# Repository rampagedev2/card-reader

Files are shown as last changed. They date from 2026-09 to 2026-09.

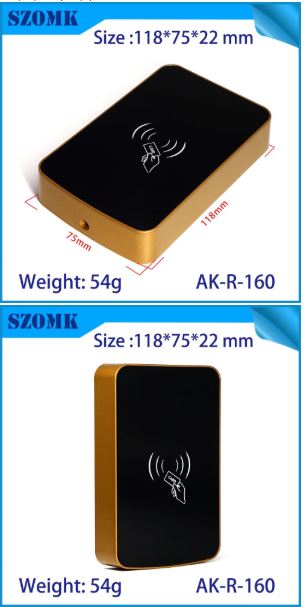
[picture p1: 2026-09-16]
enclosure/1.JPG

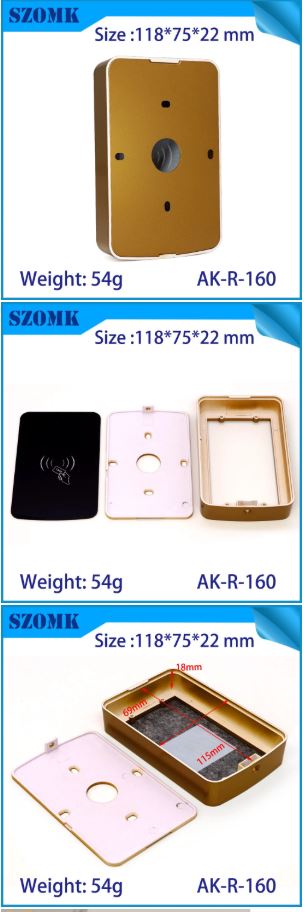
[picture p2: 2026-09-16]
enclosure/2.JPG

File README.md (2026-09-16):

# Card Reader — GD32F407VET6 + RC522

Desktop USB card reader: user **places the card on top**; RFID (RC522 module), buzzer, USB Mass Storage, ECC.

| Item | Spec |
|---|---|
| MCU | GigaDevice **GD32F407VET6** (Cortex-M4 @ 168 MHz, LQFP-100) |
| RFID | **RC522 ready module** (SPI via header J3) |
| Storage | **Custom USB MSC** (MCU internal Flash / virtual disk — no SPI NOR) |
| USB | USB-C (device FS), customized Mass Storage Class |
| Audio | Passive piezo buzzer |
| Crypto | Software ECC (secp256r1) on Cortex-M4 FPU |
| Power | USB 5 V → 3.3 V LDO |
| PCB | Fit AK-R-160 (~110 × 65 mm max), 2-layer FR-4 |
| Enclosure | **SZOMK AK-R-160** (118×75×22) — CNC card recess + LED + Type-C |

## Features

1. **Read Card** — MIFARE Classic / Ultralight / ISO14443A via SPI to MFRC522  
2. **Buzzer** — PWM-driven piezo for tap / OK / error tones  
3. **USB Mass Storage** — appears as a removable drive; card UIDs / logs written as files  
4. **ECC calculation** — sign / verify card payloads (mbedTLS / micro-ecc)

## Folder map

```
bom/           Bill of materials + pricing (qty 500, China)
docs/          Architecture, pin map, production notes
schematic/     Multi-sheet schematic (SVG + netlist)
pcb/           PCB layout, stackup, design rules
enclosure/     Mechanical design (OpenSCAD + drawings)
firmware/      Feature map / suggested stack
```

## Cost snapshot (500 units, China)

See the interactive cost canvas and `bom/BOM_500pcs.csv`.

| Category | Per unit | 500 batch |
|---|---|---|
| Electronics (parts + bare PCB) | ~$6.60 | ~$3,300 |
| AK-R-160 + CNC | ~$1.70 | ~$850 |
| **Total (hand build hardware)** | **~$8.30** | **~$4,150** |

Buy: https://www.chinaenclosure.com/products/SZOMK-Custom-IP54-abs-plastic-junction-box-RFID-enclosure-for-Card-reader-AK-R-160-118-75-22mm.html — Ops excluded.

## Quick start (hardware)

1. Review `docs/architecture.md` and `schematic/01_system.svg`  
2. Import netlist / redraw in KiCad from `schematic/` sheets  
3. Fabricate PCB per `pcb/design-rules.md` (JLCPCB recommended)  
4. Print enclosure prototype from `enclosure/card_reader_case.scad`  
5. Open `firmware/KEIL/CardReader.uvprojx` (ARMCC5, no HAL) — build & flash SWD

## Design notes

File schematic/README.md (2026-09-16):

# Schematics Index

Open SVG files in a browser, VS Code, or Inkscape.

| Sheet | File | Content |
|---|---|---|
| 01 | `01_system.svg` | Block diagram / system overview |
| 02 | `02_power.svg` | USB-C, ESD, ferrite, LDO 3.3 V |
| 03 | `03_mcu.svg` | GD32F407VET6 pin connections |
| 04 | `04_rfid.svg` | RC522 **module** header J3 wiring |
| 05 | `05_usb_flash_buzzer.svg` | Custom USB MSC, buzzer, LEDs, ECC notes |

Supporting: `netlist.txt`

## Path to Gerbers

1. Create KiCad 8 project  
2. Redraw sheets using these SVGs + `docs/pin-map.md`  
3. Assign footprints (LQFP-100, QFN-32, SOIC-8, …)  
4. Import PCB floorplan from `../pcb/pcb_layout.svg`  
5. Run DRC per `../pcb/design-rules.md`  
6. Plot Gerbers for JLCPCB  

These SVGs are **design-complete electrically** for quoting and review; KiCad redraw is the manufacturing gate.

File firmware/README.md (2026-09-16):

# Firmware — GD32F407VET6 bare-metal (no HAL) + legacy Keil

## Rules

- **No HAL / no SPL** — register-level drivers + minimal CMSIS map (`CMSIS/gd32f407_regs.h`)
- **Legacy Keil** — µVision project uses **ARM Compiler 5 (ARMCC)**, not ARMClang
- Open: `KEIL/CardReader.uvprojx`

## Build (Keil MDK)

1. Install Keil MDK-ARM with **ARMCC V5** (legacy compiler pack)
2. Open `firmware/KEIL/CardReader.uvprojx`
3. If prompted for device pack, use generic **ARMCM4_FP** (or install GigaDevice GD32F4 pack for flash algo)
4. Project → Options → Target → confirm **ARMCC V5**
5. Build (`F7`) → flash via SWD (CMSIS-DAP / J-Link)

Output: `KEIL/Objects/CardReader.hex`

## Tree

```
firmware/
  CMSIS/gd32f407_regs.h     Register map (no vendor HAL)
  Startup/startup_gd32f407.s  ARMCC startup + vectors
  Inc/                      board.h bsp.h spi_bus.h usb_msc.h
  Src/                      system / bsp / spi / usb_msc / main
  Middlewares/mfrc522/      RC522 SPI driver
  Middlewares/ecc/          ECC API (demo signer; swap micro-ecc later)
  KEIL/CardReader.uvprojx   Legacy Keil project
  KEIL/CardReader.sct       Scatter file
```

## Verification

See **[VERIFY.md](VERIFY.md)** — register-map bugs fixed; USB BOT + real ECDSA still open.

## Features wired

| Feature | Status |
|---|---|
| 8 MHz HXTAL → 168 MHz PLL + FMC WS | OK (fixed) |
| LEDs PB1/PB2 | OK |
| Buzzer PB0 TIMER2 PWM | OK (base/enable fixed) |
| SPI0 + MFRC522 4-byte UID | OK |
| Virtual FAT MSC (UID.TXT, LOG.CSV, UID.SIG) | RAM image OK |
| USBFS device enumeration / BOT | Skeleton only — not host-mountable yet |
| ECC sign on UID | Demo MAC only — not ECDSA |

## Pin map

See `docs/pin-map.md` (SPI1/SPI0 on PA4–7, RC522 RST PC4, USB PA11/12).

## Flash / debug

- SWD: PA13/PA14
- Algorithm: use GD32F4xx flash algo from GigaDevice Keil pack when available

## Optional: real ECDSA P-256

Drop [micro-ecc](https://github.com/kmackay/micro-ecc) `.c/.h` into `Middlewares/ecc/` and replace the body of `ecc_sign` / `ecc_verify` — keep the same headers so `main.c` stays unchanged.

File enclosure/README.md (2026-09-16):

# Enclosure — SZOMK AK-R-160 (selected)

Selected: **[AK-R-160](https://www.chinaenclosure.com/products/SZOMK-Custom-IP54-abs-plastic-junction-box-RFID-enclosure-for-Card-reader-AK-R-160-118-75-22mm.html)**

| | |
|--|--|
| Maker | SZOMK / Shenzhen OMK Electronics (China) |
| Part | **AK-R-160** |
| Size | **118 × 75 × 22 mm** |
| Material | ABS |
| Color | Black (custom OK) |
| Weight | 54 g |
| Battery | **None** |
| IP | IP54 |
| Contact | ivy@szomk.com.cn · https://szokm.en.alibaba.com/ |

Also: https://www.chinaenclosure.com/products/Shenzhen-new-product-abs-plastic-access-control-card-reader-118X75X22mm-enclosure-supply-AK-R-160.html

## Features we need

| Feature | How |
|---|-----|
| **Card place** | CNC lid recess **86 × 54 × 0.8 mm** (ISO card) |
| **LED** | CNC **2 × ø3.0 mm** beside recess |
| **USB Type-C** | CNC **9.0 × 3.5 mm** on end wall |
| Logo | Blank / no logo |

Height **22 mm** fits RC522 module better than AK-R-107 (17 mm). Lid fits ISO card on top.

## PCB fit

Target PCB ≈ **110 × 65 mm** max (confirm with seller CAD). Current design should be sized to this shell.

## Order wording

> SZOMK **AK-R-160**, qty 500, black, blank no logo, **no battery**.  
> CNC: lid card recess **86×54×0.8 mm**; **2× LED ø3.0 mm**; Type-C **9.0×3.5 mm**.  
> Send CAD/PDF and 1–3 sample before mass run.

## Cost (est. @500)

| Item | USD |
|---|-----|
| AK-R-160 blank | ~1.20 |
| Card recess + Type-C + 2× LED CNC | ~0.50 |
| **Enclosure** | **~$1.70** |

Parts+PCB ~$6.60 → **~$8.30 / unit**, **~$4,150 / 500**.

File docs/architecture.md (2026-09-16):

# System Architecture

**UX:** User **places the card on top** of the device (recessed lid). RC522 under the lid reads it.

## Block diagram

```
              [ CARD on top ]
                    |
 USB-C 5V -> ESD -> LDO 3.3V -+- GD32F407VET6
                              +- RC522 MODULE (under lid, antenna up)
                              +- Buzzer / LEDs
                              +- Custom USB MSC (MCU Flash/RAM)
```

## Subsystems

### MCU
GD32F407VET6, 168 MHz, USB FS device, custom MSC + software ECC.

### RFID — RC522 module (top-read)
Ready **RC522** board under the lid. Card is placed **on the top surface**, not inserted in a slot.
Wired to SPI1 via header **J3**. Module antenna faces the lid.

### USB MSC
Custom firmware; no SPI NOR.

### Buzzer / LEDs
PWM piezo + status LEDs (feedback when card is read).

### Enclosure
**SZOMK AK-R-160** (118×75×22 mm): CNC top card recess + Type-C + LEDs. China, no battery.

## Power

| Rail | Load |
|---|---|
| 5V USB | LDO in, buzzer |
| 3V3 | MCU, **RC522 module**, LEDs |

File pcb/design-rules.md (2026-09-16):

# PCB Design Rules — Card Reader Rev A

## Board

| Parameter | Value |
|---|---|
| Size | **105 × 60 mm** (fit SZOMK AK-R-160 118×75×22; confirm CAD) |
| Layers | **2** (Top signal+RF, Bottom GND+signal) |
| Thickness | 1.6 mm FR-4 |
| Copper | 1 oz (35 µm) |
| Finish | HASL lead-free (ENIG optional +$ for LQFP fine pitch) |
| Min trace / space | 0.15 / 0.15 mm (6 / 6 mil) |
| Min via | 0.3 mm drill / 0.55 mm pad |
| Mask | Green, silkscreen white |
| Fab | JLCPCB / PCBWay China |

**Recommendation:** ENIG if LQFP-100 yield concerns; HASL is OK for qty 500 with good stencil.

## Stackup

```
TOP:    Components, RF antenna, SPI, USB short runs
DIELEC: 1.5 mm FR-4 core approx
BOTTOM: Solid GND pour, few jumpers, SWD pads
```

## Floorplan (see `pcb_layout.svg`)

```
Y=60 ┌──────────────────────────────────────┐
     │  [USB-C]    LDO    ESD               │  short edge = cable side
     │           [GD32F407 LQFP100]         │
     │  Buzzer  LEDs                        │
     │  J3 header ---- RC522 MODULE (top)   │  module under lid
     │                                      │
Y=0  └──────────────────────────────────────┘
   X=0                                  X=105
```
Fit: SZOMK **AK-R-160** (118×75×22). No onboard antenna — module antenna faces lid.

## Critical constraints

1. **Antenna keep-out**: no copper, no components, no screws in 45×45 mm zone except antenna traces & matching.
2. **USB DP/DM**: length match ±2 mm; run over continuous GND; ESD within 5 mm of connector.
3. **Crystal**: within 8 mm of OSC pins; guard GND ring.
4. **Decoupling**: 100 nF under/near each VDD pair; via to GND plane immediately.
5. **Thermal**: EP pad of MFRC522 via-stitched to GND.
6. **Mounting**: 4× M2.5 holes at corners, 3.2 mm ID, keep 5 mm copper clearance from antenna zone.

## Panelization (qty 500)

- Panel 2×3 or 2×4 with V-cut or mouse bites
- Fiducials for SMT
- Tooling strips 5–8 mm

## Gerber outputs expected

`GTL GBL GTS GBS GTO GBO GKO TXT(drill) CPL(pos) BOM`

Generate from KiCad after redrawing from SVG sheets + netlist.

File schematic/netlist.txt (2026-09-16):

# Card Reader Netlist (Rev F)
# RC522 module via J3 - no discrete MFRC522 / antenna on main PCB

NET VBUS : J1.VBUS U4.IN U5.VBUS L1.1 BZ1.POS
NET 3V3 : U4.OUT U1.VDD* J3.3V3 LED*_viaR
NET GND : J1.GND U4.GND U1.VSS* J3.GND Q1.S
NET USB_DP : J1.DP U5.DP U1.PA12
NET USB_DM : J1.DM U5.DM U1.PA11
NET SPI1_SCK : U1.PA5 J3.SCK
NET SPI1_MISO : U1.PA6 J3.MISO
NET SPI1_MOSI : U1.PA7 J3.MOSI
NET SPI1_NSS : U1.PA4 J3.SDA
NET RFID_RST : U1.PC4 J3.RST
NET RFID_IRQ : U1.PC5 J3.IRQ
NET BUZZER_PWM : U1.PB0 R_BUZ.1
NET BUZZER_GATE : R_BUZ.2 Q1.G
NET BUZZER_DRV : Q1.D BZ1.NEG D1.A
NET LED_STAT : U1.PB1 R_LED1.1
NET LED_RF : U1.PB2 R_LED2.1
NET SWDIO : U1.PA13 J2.2
NET SWCLK : U1.PA14 J2.3
NET NRST : U1.NRST J2.4 R_RST.1
NET OSC_IN : U1.OSC_IN X1.1 C4.1
NET OSC_OUT : U1.OSC_OUT X1.2 C5.1
NET BOOT0 : U1.BOOT0 R_BOOT.1

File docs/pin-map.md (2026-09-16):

# Pin Map — GD32F407VET6

Package: LQFP-100. RFID via **RC522 module** (not discrete chip).

## Power / reset / clock

| Pin | Net | Notes |
|-----|-----|---|
| 11, 19, 28, 50, 75, 100 | VDD | 3V3, 100 nF each + 10 uF bulk |
| 12, 18, 27, 49, 74, 99 | VSS | GND |
| 22 | VDDA | 3V3 via ferrite + 1 uF / 100 nF |
| 21 | VSSA | GND |
| 14 | NRST | 10k pull-up, 100 nF to GND |
| 23 | OSC_IN | 8 MHz X1 |
| 24 | OSC_OUT | 8 MHz X1 |
| 94 | BOOT0 | 10k to GND |

## USB

| Pin | Net | Function |
|-----|-----|---|
| 70 | PA11 | USB_DM |
| 71 | PA12 | USB_DP |

## SWD

| Pin | Net | Function |
|-----|-----|---|
| 72 | PA13 | SWDIO |
| 76 | PA14 | SWCLK |

## SPI0 (GD32) / SPI1 (STM alias) → RC522 module (J3)

PA4–PA7 AF5 = **SPI0** on GD32F407 (same pins as STM32 “SPI1”).

| MCU pin | Net | Module pin (typical) |
|---|-----|---|
| 3V3 | 3V3 | 3.3V |
| GND | GND | GND |
| PA5 | SPI0_SCK | SCK |
| PA6 | SPI0_MISO | MISO |
| PA7 | SPI0_MOSI | MOSI |
| PA4 | SPI0_NSS | SDA |
| PC4 | RFID_RST | RST |
| PC5 | RFID_IRQ | IRQ (optional) |

**Important:** Power module from **3.3V only** (not 5V).

## User I/O

| Pin | Net | Function |
|-----|-----|---|
| PB0 | BUZZER_PWM | TIM PWM |
| PB1 | LED_STATUS | Green |
| PB2 | LED_RF | Blue |

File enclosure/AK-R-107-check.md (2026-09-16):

# AK-R-107 check (superseded)

**Selected enclosure is now AK-R-160** (118×75×22). See `enclosure/README.md`.

AK-R-107 (118×75×17) was too short for RC522. Kept for history only.

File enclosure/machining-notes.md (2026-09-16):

# Enclosure CNC / machining notes — AK-R-160

Base: **SZOMK AK-R-160**, **118 × 75 × 22 mm**, no battery.  
Buy: https://www.chinaenclosure.com/products/SZOMK-Custom-IP54-abs-plastic-junction-box-RFID-enclosure-for-Card-reader-AK-R-160-118-75-22mm.html  
Contact: ivy@szomk.com.cn

## Op A — Card place (required)

| | |
|--|--|
| Feature | Slight recess on **outside** of lid top |
| Size | 86.0 × 54.0 mm |
| Depth | 0.8 mm |
| Corner R | 3.0 |
| Center | Lid geometric center |
| Keep-out | Min remaining lid thickness 1.0 mm |

## Op B — USB Type-C

| | |
|--|--|
| Face | Short end wall (75 mm side) |
| Cutout | 9.0 × 3.5 mm |
| Z from outer bottom | Match PCB USB-C (placeholder ~11 mm to cutout center) |
| Tolerance | +0.2 / 0.0 |

## Op C — LEDs

| | |
|--|--|
| Qty | 2 (status green + RF blue) |
| Diameter | 3.0 mm |
| Location | Lid, beside card recess (not under card) |

## Sample

Approve 1–3 pcs with all CNC before 500.

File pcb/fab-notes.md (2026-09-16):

# PCB Fabrication Notes

## JLCPCB order settings (recommended)

| Field | Setting |
|---|---|
| Base Material | FR-4 |
| Layers | 2 |
| Dimensions | 105 mm × 60 mm (AK-R-160 fit) |
| Qty | 500 (or panel equivalent) |
| Thickness | 1.6 mm |
| Color | Green |
| Finish | HASL lead-free (or ENIG) |
| Copper Weight | 1 oz |
| Min via | 0.3 mm |
| Impedance | No (USB FS is tolerant) |
| Edge connector | No |
| Remove Order Number | Specify / Yes |
| Electrical Test | Yes |
| PCBA | Economic or Standard SMT |
| Parts | LCSC basic/extended (GD32 is Extended) |

## Assembly

- Side: Top only (buzzer may be TH — hand solder or select SMD piezo)
- Prefer full SMD BOM to avoid hand-solder fees
- AOI recommended for LQFP-100

## Test points (silkscreen)

| TP | Net |
|----|-----|
| TP1 | 3V3 |
| TP2 | GND |
| TP3 | VBUS |
| TP4 | RFID_IRQ |

## Coordinate file

Generate `.pos` from KiCad for pick-and-place. Origin: bottom-left board corner.

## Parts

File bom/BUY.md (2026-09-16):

# Where to buy (manual manufacture + RC522 module)

Hand-build: bare PCB from JLCPCB, parts from LCSC, **RC522 module** from Alibaba, **SZOMK AK-R-160** shell.

## China sourcing verified

Every line is buyable from **China** (no DigiKey/RS/OKW/Hammond required).

| Source | Location | What |
|---|---|---|
| [LCSC](https://www.lcsc.com/) | Shenzhen | MCU, LDO, ESD, passives, connectors, LEDs, buzzer, crystal |
| [JLCPCB](https://jlcpcb.com/) | Shenzhen | Bare 2-layer PCB |
| [Alibaba RC522](https://www.alibaba.com/product-detail/Verified-Supplier-MFRC-522-RC-522_1601798247615.html) | China sellers | RC522 RFID module |
| [SZOMK](https://www.chinaenclosure.com/products/SZOMK-Custom-IP54-abs-plastic-junction-box-RFID-enclosure-for-Card-reader-AK-R-160-118-75-22mm.html) | Shenzhen | AK-R-160 shell + CNC |

| Ref | Part | China buy | Origin note |
|-----|---|---|---|
| U1 | GD32F407VET6 | LCSC [C108421](https://www.lcsc.com/product-detail/C108421.html) | GigaDevice **Beijing** — in stock ~15k on LCSC |
| MOD1 | RC522 module | Alibaba | China OEM modules |
| U4 | AP2112K-3.3 | LCSC C51118 | Stocked on LCSC |
| U5 | USBLC6-2SC6 | LCSC C2827693 | ST or China-compat via LCSC |
| Q1 | AO3400 | LCSC C20917 | Common China SOT-23 FET |
| All passives / headers / USB-C / LEDs / buzzer / crystal | LCSC | All C-numbers below |
| PCB1 | Bare PCB | JLCPCB | China fab |
| ENC1 | AK-R-160 | SZOMK | Shenzhen factory |
| ENC_CNC | Recess + Type-C + LED | SZOMK | Same order |

**Not required:** DigiKey, Mouser, RS, OKW, Hammond, or any non-China enclosure maker.

## RFID (module — not discrete MFRC522 chip)

| Ref | Part | Buy |
|-----|---|-----|
| MOD1 | RC522 RFID module (SPI + antenna) | https://www.alibaba.com/product-detail/Verified-Supplier-MFRC-522-RC-522_1601798247615.html |
| J3 | 1x8 header for module | https://www.lcsc.com/product-detail/C124411.html |

Module pins (typical): **3.3V, RST, GND, IRQ, MISO, MOSI, SCK, SDA(NSS)** — 3.3V only (not 5V).

## Main ICs

| Ref | Part | Buy |
|-----|---|-----|
| U1 | GD32F407VET6 | https://www.lcsc.com/product-detail/C108421.html |
| U4 | AP2112K-3.3 | https://www.lcsc.com/product-detail/C51118.html |
| U5 | USB ESD USBLC6-2 | https://www.lcsc.com/product-detail/C2827693.html |
| Q1 | AO3400 | https://www.lcsc.com/product-detail/C20917.html |

## Connectors / audio / clock / LEDs

| Ref | Part | Buy |
|-----|---|-----|
| J1 | USB-C | https://www.lcsc.com/product-detail/C165948.html |
| J2 | SWD header | https://www.lcsc.com/product-detail/C124378.html |
| BZ1 | Piezo buzzer | https://www.lcsc.com/product-detail/C96590.html |
| X1 | 8 MHz crystal | https://www.lcsc.com/product-detail/C9002.html |
| LED1 | Green 0603 | https://www.lcsc.com/product-detail/C2286.html |
| LED2 | Blue 0603 | https://www.lcsc.com/product-detail/C2287.html |
| D1 | 1N4148W | https://www.lcsc.com/product-detail/C2128.html |
| L1 | Ferrite bead | https://www.lcsc.com/product-detail/C107148.html |

## Passives

| Ref | Part | Buy |
|-----|---|-----|
| C_BULK | 10uF 0805 | https://www.lcsc.com/product-detail/C15850.html |
| C_DEC | 100nF 0402 | https://www.lcsc.com/product-detail/C1525.html |
| C_XTAL | 22pF NP0 | https://www.lcsc.com/product-detail/C1555.html |
| R_CC | 5.1k | https://www.lcsc.com/product-detail/C25905.html |
| R_LED | 1k | https://www.lcsc.com/product-detail/C11702.html |
| R_BOOT / R_RST | 10k | https://www.lcsc.com/product-detail/C25744.html |
| R_BUZ | 100R | https://www.lcsc.com/product-detail/C25076.html |
| Kit | Assorted 0402 | https://www.lcsc.com/product-detail/C70098.html |

## PCB and enclosure

| Item | Buy |
|---|-----|
| Bare PCB | https://jlcpcb.com/ |
| **Shell SZOMK AK-R-160 (selected)** | https://www.chinaenclosure.com/products/SZOMK-Custom-IP54-abs-plastic-junction-box-RFID-enclosure-for-Card-reader-AK-R-160-118-75-22mm.html |
| Same model (alt page) | https://www.chinaenclosure.com/products/Shenzhen-new-product-abs-plastic-access-control-card-reader-118X75X22mm-enclosure-supply-AK-R-160.html |
| SZOMK Alibaba | https://szokm.en.alibaba.com/ |

**118×75×22 mm**, China, no battery. CNC: card recess + Type-C + 2× LED. ivy@szomk.com.cn

## Cost (hardware only)

| | Buy 1 | Buy 500 (per device) | 500 batch |
|--|---|---|---|
| Parts + bare PCB | ~$8.36 | ~$6.60 | ~$3,300 |
| AK-R-160 + CNC | ~$6.00 | ~$1.70 | ~$850 |
| **Total** | **~$14.36** | **~$8.30** | **~$4,150** |

Buy-1 uses LCSC/Alibaba sample or MOQ prices (see `Unit_USD_1` / `Ext_USD_1` in `BOM_500pcs.csv`).

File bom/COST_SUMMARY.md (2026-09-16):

# Production Cost Summary

## Selected enclosure

**SZOMK AK-R-160** 118×75×22 mm:  
https://www.chinaenclosure.com/products/SZOMK-Custom-IP54-abs-plastic-junction-box-RFID-enclosure-for-Card-reader-AK-R-160-118-75-22mm.html  

| Metric | Buy 1 | Buy 500 |
|---|---|---|
| **Cost per device** | **~$14.36** | **~$8.30** |
| **Batch total** | **~$14.36** | **~$4,150** |

- **Buy 1:** LCSC/Alibaba/JLCPCB sample or MOQ tiers (MCU LCSC 1+ $4.31; PCB $2/5 ≈ $0.40 ea; enclosure sample + CNC).
- **Buy 500:** volume breaks from `BOM_500pcs.csv`.
- Enclosure @500 ~$1.70 (blank + CNC). Ops excluded.

**China sourcing:** all lines from LCSC + JLCPCB + Alibaba + SZOMK — see `bom/CHINA_SOURCING.md`.

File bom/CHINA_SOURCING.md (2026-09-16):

# China purchase checklist — 500 devices

All hardware from China. Ops (pack/test) excluded.

## Order 1 — LCSC (Shenzhen) — electronics

Cart these LCSC part numbers (qty ×500 unless noted):

| LCSC | Part | Qty/device |
|---|---|---|
| C108421 | GD32F407VET6 | 1 |
| C51118 | AP2112K-3.3 | 1 |
| C2827693 | USBLC6-2SC6 | 1 |
| C20917 | AO3400 | 1 |
| C9002 | 8 MHz crystal | 1 |
| C96590 | Piezo buzzer | 1 |
| C165948 | USB-C 16P | 1 |
| C124378 | SWD 1x4 | 1 |
| C124411 | Header 1x8 | 1 |
| C2286 / C2287 | LED green / blue | 1 each |
| C2128 | 1N4148W | 1 |
| C107148 | Ferrite 0603 | 1 |
| C15850 | 10uF 0805 | 4 |
| C1525 | 100nF 0402 | 16 |
| C1555 | 22pF | 2 |
| C25905 | 5.1k | 2 |
| C11702 | 1k | 2 |
| C25744 | 10k | 2 |
| C25076 | 100R | 1 |
| C70098 | Assorted kit (optional) | 1 |

MCU verify: https://www.lcsc.com/product-detail/C108421.html (China stock).

## Order 2 — Alibaba — RC522 module ×500

https://www.alibaba.com/product-detail/Verified-Supplier-MFRC-522-RC-522_1601798247615.html  
3.3V SPI module with antenna.

## Order 3 — JLCPCB — bare PCB ×500

https://jlcpcb.com/ — 2-layer, ~105×60 mm, Gerbers from `pcb/`.

## Order 4 — SZOMK — AK-R-160 ×500 + CNC

https://www.chinaenclosure.com/products/SZOMK-Custom-IP54-abs-plastic-junction-box-RFID-enclosure-for-Card-reader-AK-R-160-118-75-22mm.html  
Alibaba: https://szokm.en.alibaba.com/ · ivy@szomk.com.cn  
CNC: card recess 86×54×0.8 + Type-C + 2× LED.

## Result

| Bucket | China? |
|---|---|
| MCU / ICs / passives | Yes — LCSC |
| RC522 module | Yes — Alibaba |
| Bare PCB | Yes — JLCPCB |
| Enclosure + CNC | Yes — SZOMK Shenzhen |

**Verdict: all purchasable from China.**

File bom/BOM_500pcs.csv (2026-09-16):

Ref | Qty | Value | Package | Manufacturer | LCSC_MPN | Unit_USD_1 | Ext_USD_1 | Unit_USD_500 | Ext_USD_500 | Category | Buy_URL | Notes
U1 | 1 | GD32F407VET6 | LQFP-100 | GigaDevice | C108421 | 4.31 | 4.31 | 2.90 | 2.90 | MCU | https://www.lcsc.com/product-detail/C108421.html | LCSC 1+ $4.31; 540+ ~$3.05; Hand solder LQFP
MOD1 | 1 | RC522 RFID module | 40x60 module | generic | n/a | 1.20 | 1.20 | 0.55 | 0.55 | RFID | https://www.alibaba.com/product-detail/Verified-Supplier-MFRC-522-RC-522_1601798247615.html | Sample ~$1.20; volume ~$0.55; SPI+antenna
J3 | 1 | Header 1x8 2.54 female | Pin header | generic | C124411 | 0.10 | 0.10 | 0.05 | 0.05 | Connector | https://www.lcsc.com/product-detail/C124411.html | RC522 socket or solder wires
U4 | 1 | AP2112K-3.3TRG1 | SOT-23-5 | BCI/Diodes | C51118 | 0.18 | 0.18 | 0.08 | 0.08 | Power | https://www.lcsc.com/product-detail/C51118.html | LCSC MOQ 5 @ ~$0.18; 500+ ~$0.11
U5 | 1 | USBLC6-2SC6 | SOT-23-6 | ST/compat | C2827693 | 0.28 | 0.28 | 0.12 | 0.12 | ESD | https://www.lcsc.com/product-detail/C2827693.html | USB ESD
Q1 | 1 | AO3400 | SOT-23 | AOS/compat | C20917 | 0.08 | 0.08 | 0.03 | 0.03 | Discrete | https://www.lcsc.com/product-detail/C20917.html | Buzzer MOSFET
X1 | 1 | 8MHz 20ppm | SMD3225 | generic | C9002 | 0.12 | 0.12 | 0.05 | 0.05 | Clock | https://www.lcsc.com/product-detail/C9002.html | HSE crystal
BZ1 | 1 | Passive piezo 12mm | TH | generic | C96590 | 0.35 | 0.35 | 0.15 | 0.15 | Audio | https://www.lcsc.com/product-detail/C96590.html | Easy hand solder TH
J1 | 1 | USB-C 16P SMD | TYPE-C | generic | C165948 | 0.19 | 0.19 | 0.18 | 0.18 | Connector | https://www.lcsc.com/product-detail/C165948.html | LCSC MOQ 5 @ ~$0.19
J2 | 1 | SWD 1x4 2.54 | Pin header | generic | C124378 | 0.10 | 0.10 | 0.05 | 0.05 | Debug | https://www.lcsc.com/product-detail/C124378.html | Programming header
LED1 | 1 | Green 0603 | LED-0603 | generic | C2286 | 0.03 | 0.03 | 0.02 | 0.02 | Opto | https://www.lcsc.com/product-detail/C2286.html | Status LED
LED2 | 1 | Blue 0603 | LED-0603 | generic | C2287 | 0.03 | 0.03 | 0.02 | 0.02 | Opto | https://www.lcsc.com/product-detail/C2287.html | RF LED
D1 | 1 | 1N4148W | SOD-123 | generic | C2128 | 0.03 | 0.03 | 0.01 | 0.01 | Discrete | https://www.lcsc.com/product-detail/C2128.html | Buzzer diode
L1 | 1 | Ferrite 600R@100MHz | 0603 | generic | C107148 | 0.05 | 0.05 | 0.02 | 0.02 | EMI | https://www.lcsc.com/product-detail/C107148.html | USB VBUS ferrite
C_BULK | 4 | 10uF 16V X5R | 0805 | generic | C15850 | 0.06 | 0.24 | 0.03 | 0.12 | Passive | https://www.lcsc.com/product-detail/C15850.html | Bulk caps
C_DEC | 16 | 100nF 50V X7R | 0402 | generic | C1525 | 0.01 | 0.16 | 0.005 | 0.08 | Passive | https://www.lcsc.com/product-detail/C1525.html | Decoupling
C_XTAL | 2 | 22pF NP0 | 0402 | generic | C1555 | 0.02 | 0.04 | 0.01 | 0.02 | Passive | https://www.lcsc.com/product-detail/C1555.html | Crystal load
R_CC | 2 | 5.1k 1% | 0402 | generic | C25905 | 0.01 | 0.02 | 0.005 | 0.01 | Passive | https://www.lcsc.com/product-detail/C25905.html | USB-C CC resistors
R_LED | 2 | 1k 5% | 0402 | generic | C11702 | 0.01 | 0.02 | 0.004 | 0.008 | Passive | https://www.lcsc.com/product-detail/C11702.html | LED series
R_BOOT | 1 | 10k 5% | 0402 | generic | C25744 | 0.01 | 0.01 | 0.004 | 0.004 | Passive | https://www.lcsc.com/product-detail/C25744.html | BOOT0 pull-down
R_RST | 1 | 10k 5% | 0402 | generic | C25744 | 0.01 | 0.01 | 0.004 | 0.004 | Passive | https://www.lcsc.com/product-detail/C25744.html | NRST pull-up
R_BUZ | 1 | 100R 5% | 0402 | generic | C25076 | 0.01 | 0.01 | 0.004 | 0.004 | Passive | https://www.lcsc.com/product-detail/C25076.html | Gate series
MISC_PASS | 1 | Extra 0402 kit | 0402 | generic | C70098 | 0.40 | 0.40 | 0.25 | 0.25 | Passive | https://www.lcsc.com/product-detail/C70098.html | Assorted R/C kit if preferred
PCB1 | 1 | Bare PCB 2-layer | FR-4 | JLCPCB | n/a | 0.40 | 0.40 | 0.30 | 0.30 | Fab | https://jlcpcb.com/ | Buy-1 = $2/5pcs promo (~$0.40 ea); 500 ~$0.30
 |  |  |  |  |  |  | PARTS_SUBTOTAL |  | 8.36 | 8.36 | 6.60 | 6.60 |  | RC522 module; hand assemble; no factory SMT
ENC1 | 1 | SZOMK AK-R-160 selected China | 118x75x22 ABS | SZOMK | AK-R-160 | 3.50 | 3.50 | 1.20 | 1.20 | Mech | https://www.chinaenclosure.com/products/SZOMK-Custom-IP54-abs-plastic-junction-box-RFID-enclosure-for-Card-reader-AK-R-160-118-75-22mm.html | Sample ~$3.50; volume ~$1.20
ENC_CNC | 1 | Card recess + Type-C + 2x LED CNC | Labor | SZOMK | n/a | 2.50 | 2.50 | 0.50 | 0.50 | Mech | https://szokm.en.alibaba.com/ | Sample CNC higher; ask with quote
ENC_ALT | 0 | SZOMK AK-R-55 larger alt | 154x110x35 | SZOMK | AK-R-55 | 4.00 | 0.00 | 1.50 | 0.00 | Mech | https://szomkbox.en.made-in-china.com/product/pvYQDhkWTxAn/China-Szomk-Card-Reader-Housing-for-Electronics-RFID-Project-Box.html | Roomier alt; qty0
SCREW | 1 | Included with enclosure | Steel | SZOMK | n/a | 0.00 | 0.00 | 0.00 | 0.00 | Mech | n/a | Comes with kit
 |  |  |  |  |  |  | UNIT_TOTAL_EST |  | 14.36 | 14.36 | 8.30 | 8.30 |  | Parts+PCB+AK-R-160; Ops excluded
 |  |  |  |  |  |  | BATCH_1_TOTAL |  | 14.36 | 14.36 |  |  | One device at sample/MOQ prices
 |  |  |  |  |  |  | BATCH_500_TOTAL |  |  |  | 4150 | 4150
 |  |  |  |  |  |  | MOLD_NRE |  | 0 | 0 | 0 | 0 |  | Not purchased
 |  |  |  |  |  |  | FACTORY_SMT |  | 0 | 0 | 0 | 0 |  | Manual manufacture - not ordered

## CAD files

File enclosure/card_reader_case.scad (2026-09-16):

// Card Reader Enclosure reference — SZOMK AK-R-160 (118x75x22)
// OpenSCAD mockup for visual / 3D-print prototype
// Units: mm

outer_l = 118;
outer_w = 75;
outer_h = 22;
wall = 2.0;
fillet = 4;
bottom_h = 12;
top_h = outer_h - bottom_h;

// Card recess on lid outer surface
card_l = 86;
card_w = 54;
card_depth = 0.8;
card_r = 3;

// USB Type-C cutout on short edge
usb_w = 9.0;
usb_h = 3.5;
usb_z = 11.0; // center height from bottom — tune to PCB

module rounded_rect(l, w, h, r) {
  hull() {
    for (x = [-l/2+r, l/2-r])
      for (y = [-w/2+r, w/2-r])
        translate([x, y, 0]) cylinder(h=h, r=r, $fn=40);
  }
}

module bottom() {
  difference() {
    rounded_rect(outer_l, outer_w, bottom_h, fillet);
    translate([0, 0, wall])
      rounded_rect(outer_l-2*wall, outer_w-2*wall, bottom_h, max(1, fillet-1));
    // Type-C on +X short face
    translate([outer_l/2, 0, usb_z])
      cube([wall*3, usb_w, usb_h], center=true);
  }
}

module top() {
  difference() {
    rounded_rect(outer_l, outer_w, top_h, fillet);
    translate([0, 0, -0.1])
      rounded_rect(outer_l-2*wall, outer_w-2*wall, top_h-wall+0.2, max(1, fillet-1));
    // Card indentation on outer top
    translate([0, 0, top_h - card_depth])
      rounded_rect(card_l, card_w, card_depth+0.2, card_r);
    // LED holes
    translate([-outer_l/2+12, outer_w/2-10, 0])
      cylinder(h=top_h+1, r=1.5, $fn=24);
    translate([-outer_l/2+20, outer_w/2-10, 0])
      cylinder(h=top_h+1, r=1.5, $fn=24);
  }
}

translate([0, 0, 0]) bottom();
translate([0, 0, bottom_h + 0.3]) color([0.18,0.18,0.2]) top();

// bottom();
// top();

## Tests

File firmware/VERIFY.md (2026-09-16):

# Firmware verification

Audit date: 2026-09-15. Against GD32F4xx CMSIS / datasheet (RCU AHB1EN @ 0x30, TIMER2 @ 0x40000400, USBFS AHB2EN bit7).

## Verdict

**Clock / GPIO / SPI / RC522 / TIMER2 / SysTick / vector table: corrected and structurally sound.**  
**USB MSC host mount and real ECDSA: not production-ready** (stubs / demo MAC).

## Bugs found and fixed

| Issue | Impact | Fix |
|---|---|-----|
| RCU struct used wrong offsets (`AHBEN` like F1) | Clocks never enabled | `AHB1EN`/`AHB2EN`/`APB1EN`/`APB2EN` layout |
| USBFS clock on wrong enable bit | USBFS dead | `RCU_AHB2EN` bit 7 |
| TIMER2 base / enable wrong | Buzzer silent or wrong timer | Base `0x40000400`, `APB1EN` bit 1 |
| FPU via `SCB->CCR` | Illegal; faults with FP ABI | `CPACR` CP10/CP11 |
| No FMC wait states @ 168 MHz | Unstable Flash fetch | `FMC->WS = 5` |
| IRQ vectors 0..66 = 0 | Spurious IRQ → HardFault | `Default_Handler` |
| `hash_uid` `% uid->size` if size 0 | Div-by-zero | Guard `n = size ? size : 1` |

## Still incomplete (by design / next work)

1. **USBFS MSC** — clock, soft-connect, IRQ shell only. No EP0 SETUP, no BOT (CBW/CSW), so host will **not** mount the FAT disk yet. RAM FAT builder itself is OK.
2. **ECC** — `ecc_sign` is a keyed XOR demo, **not** ECDSA P-256. Swap in micro-ecc (or similar) behind the same API.
3. **RC522** — REQA + anticoll cascade level 1 only (4-byte UID). No cascade 2/3 (7/10-byte UIDs), no HALT A.
4. **Hardware bring-up** — not run on silicon in this audit; needs Keil build + SWD check of VERSION (`0x91`/`0x92`) and USB enumerate.

## What should work after flash (expected)

- 8 MHz HXTAL → PLL 168 MHz, APB1 42 / timers 84, PLLQ → 48 MHz USB clock source
- LEDs PB1/PB2, buzzer PWM on PB0 TIMER2_CH2
- SPI0 @ PA4–7 ↔ RC522; UID read for classic 4-byte cards
- On card: update in-RAM `UID.TXT` / `LOG.CSV` / `UID.SIG` (visible once USB BOT is finished)

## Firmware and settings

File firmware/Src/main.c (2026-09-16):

/**
 * @file main.c — Card reader application (bare-metal, no HAL)
 *
 * Flow: init → poll RC522 → on UID update MSC files + ECC sign + beep
 */
#include "bsp.h"
#include "board.h"
#include "mfrc522.h"
#include "ecc_p256.h"
#include "usb_msc.h"
#include <string.h>

static void hash_uid(const mfrc522_uid_t *uid, uint8_t out[32])
{
    uint32_t i;
    uint8_t n = uid->size ? uid->size : 1U;
    memset(out, 0, 32);
    for (i = 0; i < uid->size && i < 32U; i++)
        out[i] = uid->uid[i];
    for (; i < 32U; i++)
        out[i] = (uint8_t)(0xA5u ^ (uint8_t)i ^ out[i % n]);
}

int main(void)
{
    mfrc522_uid_t uid;
    uint8_t hash[32];
    uint8_t sig[64];
    char line[48];
    uint32_t last_poll = 0;
    uint8_t last_uid[10];
    uint8_t last_len = 0;

    /* SystemInit already ran from Reset_Handler */
    board_init();
    ecc_init();
    (void)ecc_load_or_create_key();
    mfrc522_init();
    usb_msc_init();

    led_status(1);
    if (mfrc522_pcd_is_ready())
        buzzer_ok();
    else
        buzzer_err();

    for (;;) {
        usb_msc_poll();

        if ((millis() - last_poll) < 50U)
            continue;
        last_poll = millis();

        if (!mfrc522_picc_is_new_card_present()) {
            led_rf(0);
            continue;
        }

        if (mfrc522_picc_read_card_serial(&uid) != MFRC522_OK) {
            buzzer_err();
            continue;
        }

        /* Debounce same card */
        if (last_len == uid.size && memcmp(last_uid, uid.uid, uid.size) == 0) {
            mfrc522_picc_halt();
            continue;
        }
        memcpy(last_uid, uid.uid, uid.size);
        last_len = uid.size;

        led_rf(1);
        usb_msc_set_uid(uid.uid, uid.size);

        {
            uint8_t i, n = 0;
            static const char hex[] = "0123456789ABCDEF";
            line[n++] = '0';
            line[n++] = ',';
            for (i = 0; i < uid.size && n < 40U; i++) {
                line[n++] = hex[uid.uid[i] >> 4];
                line[n++] = hex[uid.uid[i] & 0xFU];
            }
            line[n] = 0;
            usb_msc_append_log(line);
        }

        hash_uid(&uid, hash);
        if (ecc_sign(hash, sig))
            usb_msc_set_signature(sig, 64);

        buzzer_ok();
        mfrc522_picc_halt();
        delay_ms(300);
        led_rf(0);
    }
}

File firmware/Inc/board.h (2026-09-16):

#ifndef BOARD_H
#define BOARD_H

/* Pin map — GD32F407VET6 + RC522 module (see docs/pin-map.md) */

#define LED_STATUS_PORT   GPIOB
#define LED_STATUS_PIN    1U   /* PB1 green */
#define LED_RF_PORT       GPIOB
#define LED_RF_PIN        2U   /* PB2 blue */

#define BUZZER_PORT       GPIOB
#define BUZZER_PIN        0U   /* PB0 TIMER2_CH2 AF2 */

#define RFID_NSS_PORT     GPIOA
#define RFID_NSS_PIN      4U   /* PA4 */
#define RFID_SCK_PORT     GPIOA
#define RFID_SCK_PIN      5U
#define RFID_MISO_PORT    GPIOA
#define RFID_MISO_PIN     6U
#define RFID_MOSI_PORT    GPIOA
#define RFID_MOSI_PIN     7U
#define RFID_RST_PORT     GPIOC
#define RFID_RST_PIN      4U   /* PC4 */
#define RFID_IRQ_PORT     GPIOC
#define RFID_IRQ_PIN      5U   /* PC5 */

#define USB_DM_PIN        11U  /* PA11 */
#define USB_DP_PIN        12U  /* PA12 */

#endif

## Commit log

2026-09-16 Update README.md to clarify card reader specifications and pricing details, including changes to RFID module description and enclosure information.
2026-09-16 Add bare-metal GD32F407 firmware and fix register map.
    Include Keil ARMCC5 project, RC522/SPI/USB MSC scaffold, and verification notes for RCU/TIMER/USBFS corrections.
    [board.h, bsp.c, main.c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]
